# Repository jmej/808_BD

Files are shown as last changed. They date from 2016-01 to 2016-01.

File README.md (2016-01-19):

# 808 kick drum from μ-rave 

[jmej](http://www.anestheticaudio.com/), [xnor](http://x37v.info)

## Notes

This is a near exact clone of the famous kick drum from the classic tr-808 drum
machine. The only changes are for facilitating the common mods (extended decay
and a pitch pot), and a slightly more flexible trigger input.

This can be triggered by a trigger output of a drum machine, or by a CV/Trigger
from a modular synth, a cmos square wave, or even a loud audio transient.
Alternatively you could wire a switch or button to send the trigger input high
as well. (Basically a quick +V to the trigger input does the job).

It runs on +/- power supply, you can run 2 9v batteries in series, or run it
off a bipolar (+/-15v or +/-12v power supply). Or... experiment!

The accent has a pull-up so if you'll have max volume if its not driven otherwise.

This is an easy and cheap build.

## Build Docs
[muffwiggler build thread](http://www.muffwiggler.com/forum/viewtopic.php?t=54149)

## BOM
XXX EDIT THIS FOR NEW VERSION
[Old Mouser BOM](http://www.mouser.com/ProjectManager/ProjectDetail.aspx?AccessID=950b04d9fc)

## Purchase
[tindie](https://www.tindie.com/products/jmej/808-kick-drum-clone-pcb/)

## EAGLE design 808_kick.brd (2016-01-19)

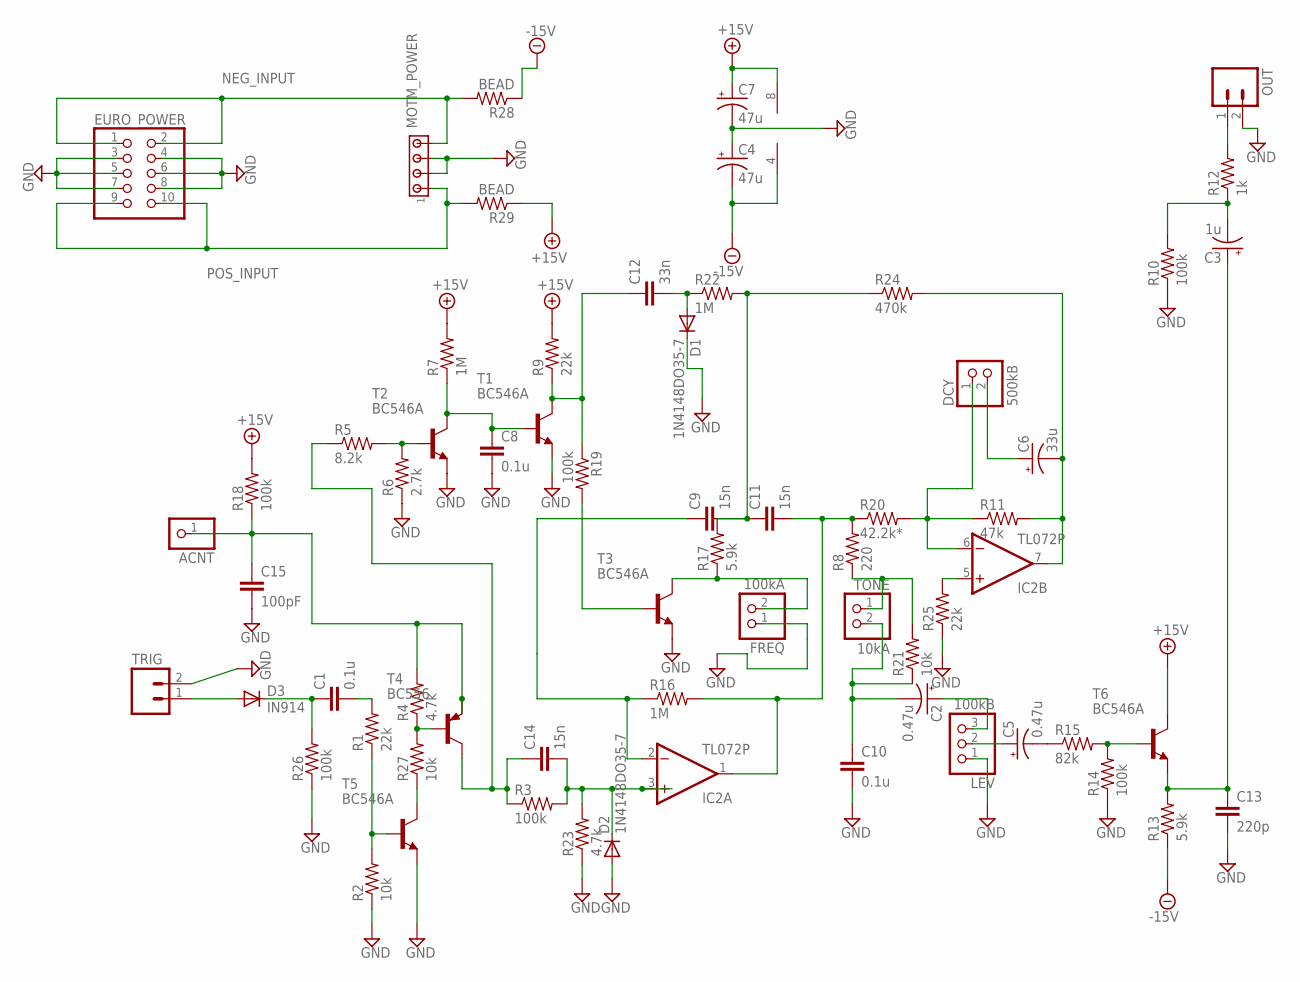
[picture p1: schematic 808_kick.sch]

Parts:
ACNT: PINHD-1X1; 1X01
C1: 0.1u; C2.5-3
C2, C5: 0.47u; CPOL-RADIAL-100UF-25V
C3: 1u; CPOL-RADIAL-100UF-25V
C4, C7: 47u; E2-5
C6: 33u; CPOL-RADIAL-100UF-25V
C8, C10: 0.1u; C2.5-2
C9, C11, C14: 15n; C2.5-2
C12: 33n; C2.5-2
C13: 220p; C2.5-2
C15: 100pF; C2.5-2
D1, D2: 1N4148DO35-7; DO35-7
D3: IN914; DO35-7
DCY: 500kB; 1X02
EURO_POWER: PINHD-2X5; 2X05
FREQ: 100kA; 1X02
IC2: TL072P; DIL08
LEV: 100kB; 1X03
MOTM_POWER: MTA04-156; 1X4MTA
OUT: M02; 1X02_LONGPADS
R1, R9, R25: 22k; 0411V
R2, R21, R27: 10k; 0411V
R3, R10, R14, R18, R19, R26: 100k; 0411V
R4, R23: 4.7k; 0411V
R5: 8.2k; 0411V
R6: 2.7k; 0411V
R7, R16, R22: 1M; 0411V
R8: 220; 0411V
R11: 47k; 0411V
R12: 1k; 0411V
R13, R17: 5.9k; 0411V
R15: 82k; 0411V
R20: 42.2k*; 0411V
R24: 470k; 0411V
R28, R29: BEAD; 0411V
T1, T2, T3, T5, T6: BC546A; TO92-EBC
T4: BC556; TO92-EBC
TONE: 10kA; 1X02
TRIG: M02; 1X02_LONGPADS

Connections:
+15V: C7.+, IC2.8 (V+), R7.2, R9.2, R18.2, R29.1, T6.C
-15V: C4.-, IC2.4 (V-), R13.1, R28.1
GND: C4.+, C7.-, C8.2, C10.2, C13.2, C15.2, D1.C, D2.A, EURO_POWER.3, EURO_POWER.4, EURO_POWER.5, EURO_POWER.6, EURO_POWER.7, EURO_POWER.8, FREQ.1, LEV.1, MOTM_POWER.2, MOTM_POWER.3, OUT.2, R2.1, R6.1, R10.1, R14.1, R23.1, R25.1, R26.1, T1.E, T2.E, T3.E, T5.E, TRIG.2
unnamed: D3.A, TRIG.1
unnamed: R1.1, R2.2, T5.B
unnamed: R4.1, R27.2, T4.B
unnamed: ACNT.1, C15.1, R4.2, R18.1, T4.E
unnamed: C14.1, R3.1, R5.1, T4.C
unnamed: C14.2, D2.C, IC2.3 (+IN), R3.2, R23.2
unnamed: FREQ.2, R17.1, T3.C
unnamed: C9.1, IC2.2 (-IN), R16.1
unnamed: C6.1 (+), DCY.2
unnamed: R5.2, R6.2, T2.B
unnamed: C8.1, R7.1, T1.B, T2.C
unnamed: OUT.1, R12.2
unnamed: C12.1, R9.1, R19.1, T1.C
unnamed: C12.2, D1.A, R22.1
unnamed: C3.1 (+), C13.1, R13.2, T6.E
unnamed: C9.2, C11.1, R17.2, R22.2, R24.1
unnamed: R14.2, R15.2, T6.B
unnamed: C1.1, D3.C, R26.2
unnamed: C5.2 (-), R15.1
unnamed: C3.2 (-), R10.2, R12.1
unnamed: R19.2, T3.B
unnamed: R27.1, T5.C
unnamed: C11.2, IC2.1 (OUT), R8.2, R16.2, R20.1
unnamed: R8.1, R21.2, TONE.1
unnamed: IC2.5 (+IN), R25.2
unnamed: C5.1 (+), LEV.2
unnamed: C6.2 (-), IC2.7 (OUT), R11.2, R24.2
unnamed: C1.2, R1.2
unnamed: DCY.1, IC2.6 (-IN), R11.1, R20.2
unnamed: C2.1 (+), LEV.3
unnamed: C2.2 (-), C10.1, R21.1, TONE.2
NEG_INPUT: EURO_POWER.1, EURO_POWER.2, MOTM_POWER.4, R28.2
POS_INPUT: EURO_POWER.9, EURO_POWER.10, MOTM_POWER.1, R29.2

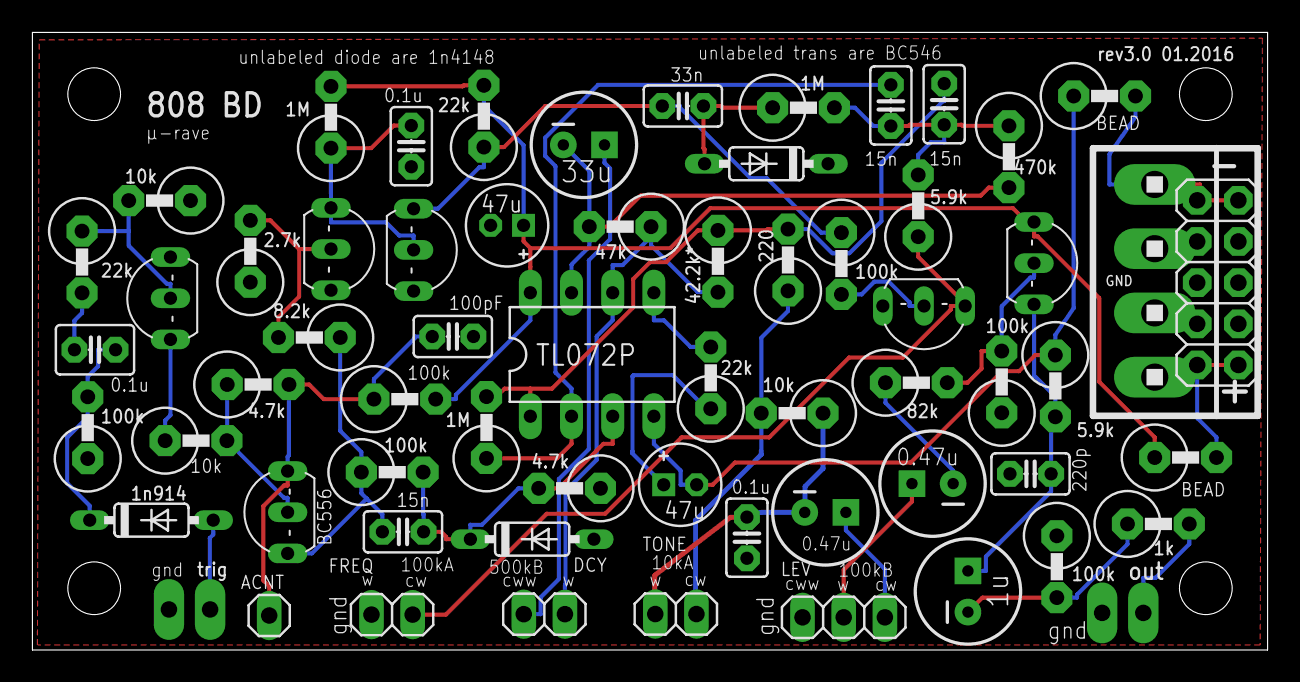
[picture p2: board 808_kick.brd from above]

Board: 2 copper layers, 76.2 x 38.1 mm, 63 parts (0 on the bottom side), 36 nets.

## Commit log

2016-01-15 added pullup for accent input
    so it'll be normally high
    [808_kick_rev2.2.brd, 808_kick_rev2.2.sch]
2016-01-15 cleaned up the schematic a little bit
    [808_kick_rev2.2.sch]
2016-01-15 added MOTM style power
    [808_kick_rev2.2.brd, 808_kick_rev2.2.sch]
2016-01-15 ignoring lock files
    [808_kick_rev2.2.sch]
2016-01-16 added euro power
    [808_kick_rev2.2.sch]
2016-01-16 board layout, increased size too
    [808_kick_rev2.2.brd]
2016-01-16 cleaned up the project, took version out of project files
    [808_kick.brd, 808_kick.sch]
2016-01-16 moved stuff around on the schematic just to be more clear
    [808_kick.sch]
2016-01-16 ditched some labels
    [808_kick.brd]
2016-01-16 converted pot i/o into 2 pin when there were 2 ganged pins
    I'd gang the pot on the pot itself anyways
    [808_kick.brd, 808_kick.sch]
2016-01-16 minor edits
    [808_kick.brd, 808_kick.sch]
2016-01-17 fixed up some layers for oshpark
    [808_kick.brd]
2016-01-17 moved the bead a little further away from the screw hole
    [808_kick.brd]
2016-01-17 moved the trig further away from screw hole
    [808_kick.brd]
2016-01-17 swapped tone pins, labeled pot connections
    [808_kick.brd, 808_kick.sch]
